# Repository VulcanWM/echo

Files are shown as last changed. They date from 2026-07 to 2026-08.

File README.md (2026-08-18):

# Echo

This is my first hardware project, in which I made a Simon Says game by designing a PCB and writing the firmware for it.

The components involved are a XIAO RP2040 as the microcontroller, 3 switches which represent the possible options the player has to press, 3 different coloured LEDs that light up when introducing the sequence, resistors to stop the LEDs from receiving too much current, and a buzzer so the game is not just vision-based but also audio-based.

There is also a CAD-designed case, consisting only of a bottom section. I felt that a top cover was unnecessary, as the buttons and LEDs need to remain clearly visible and accessible. The bottom case mainly protects the PCB while making the device easier and more comfortable to hold. There are 4 mounting holes so that the PCB can be securely attached to standoffs in the case using screws.

How the game works is:
- You press any button to start.
- It gives you a sequence of length 1 (while playing a tone and lighting up the corresponding LED).
- You then have to press the button that corresponds to the LED that just lit up.
- If you get that right, you are given a sequence of length 2, with one extra note added to the previous sequence.
- The game keeps going until you either get the sequence wrong (and hear a losing tune I created), or reach 100 rounds (and hear a victory tune I created).

I made it because I spend a lot of time on devices, so whenever I've been using one continuously for around an hour, I can take a break by playing this game. Since it's a memory game, it also helps me improve my focus.

## Images

The KiCad source files (`.kicad_pro`, `.kicad_sch`, `.kicad_pcb`) and `gerbers.zip` used to manufacture the PCB are located in the [`pcb-files`](pcb-files) folder.

This is what the schematic looks like:

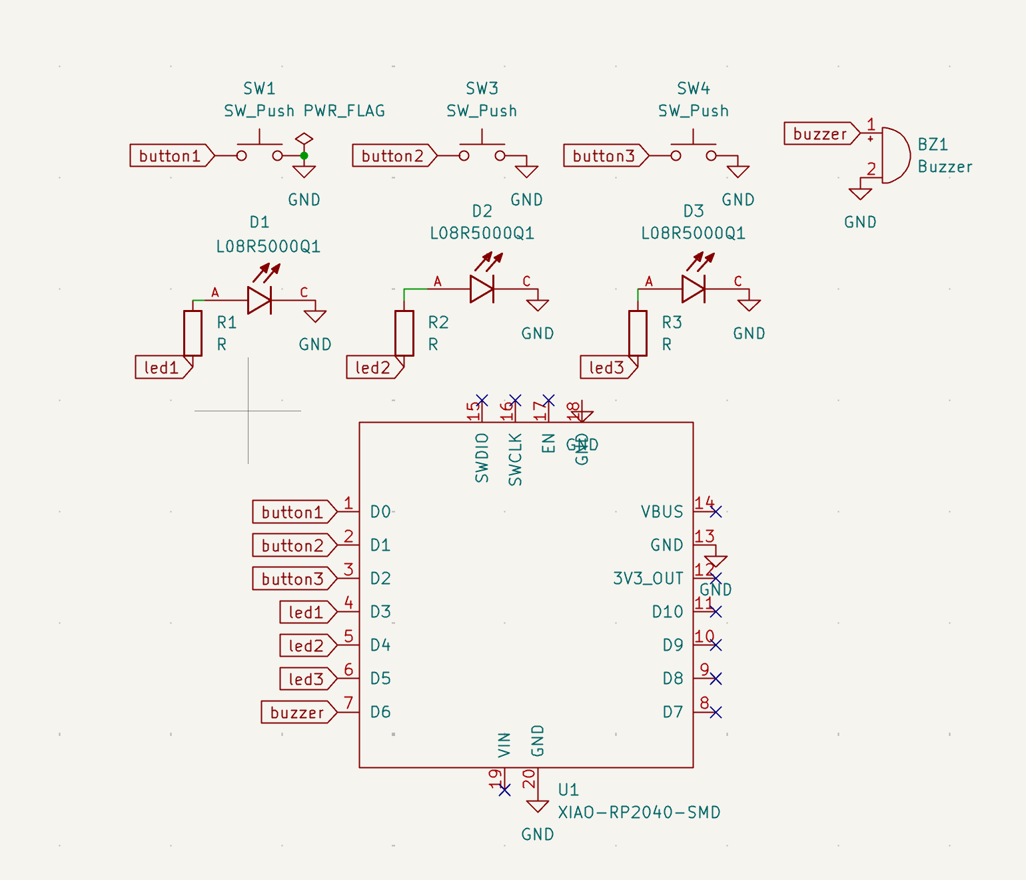
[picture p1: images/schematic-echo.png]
schematic


This is what the PCB looks like:

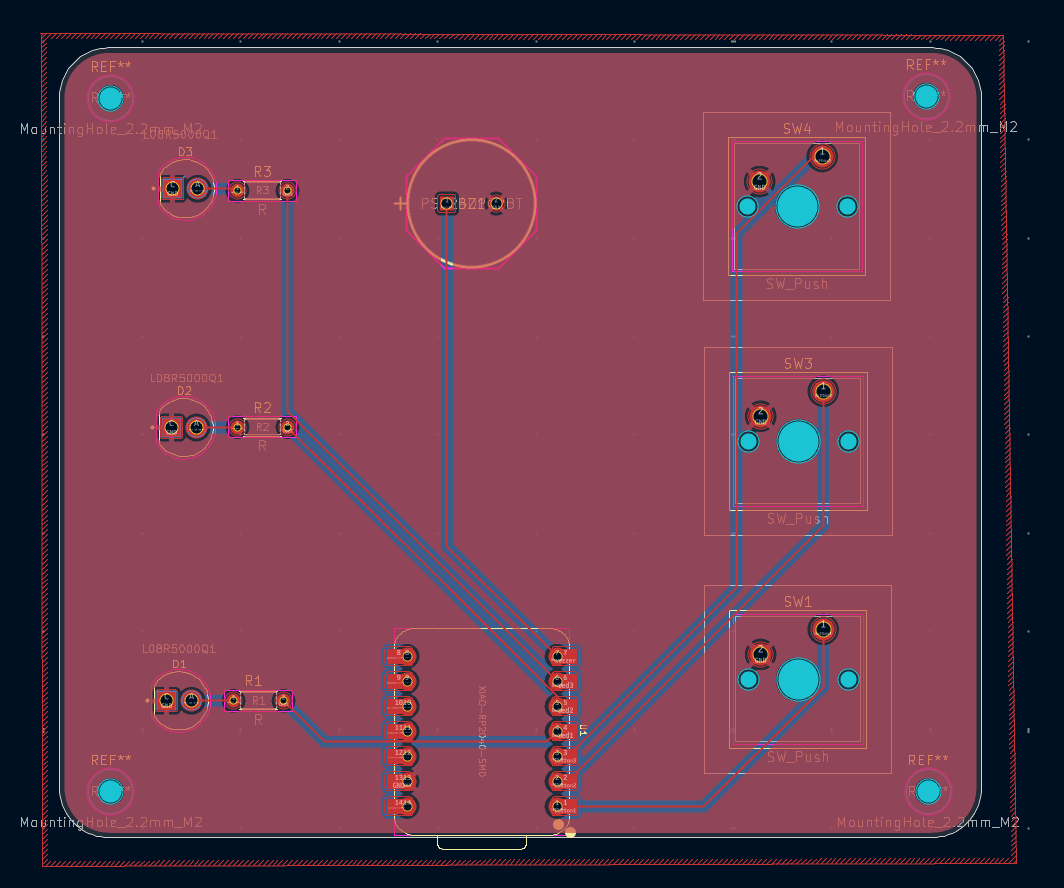
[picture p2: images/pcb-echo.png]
pcb


This is what the PCB looks like in the 3D renderer:

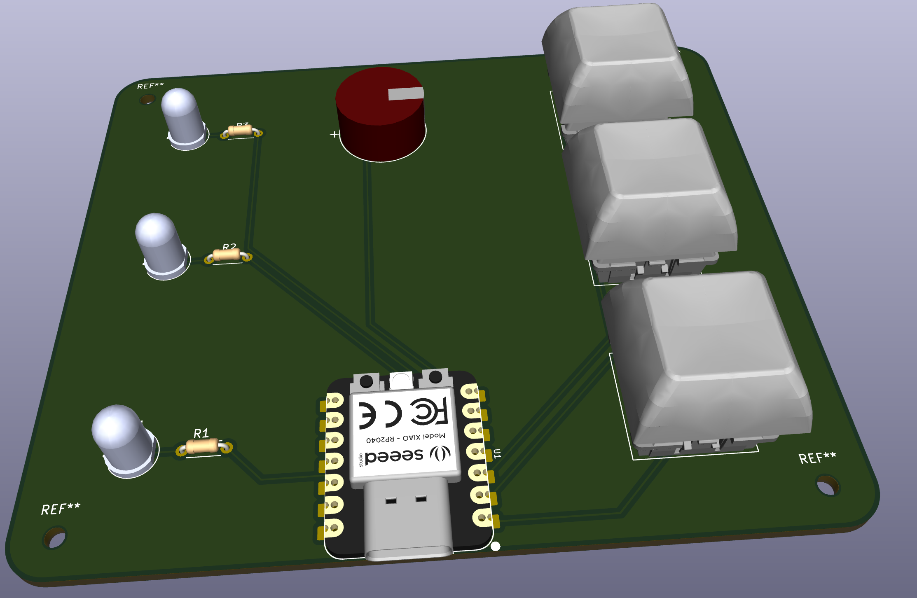
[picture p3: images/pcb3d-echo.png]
pcb 3d


The Fusion CAD source files (`.step`, `.stl`, `.f3d`) used to manufacture the case can be found in the [`case-files`](case-files) folder.

This is what the case looks like (with the PCB inside it):

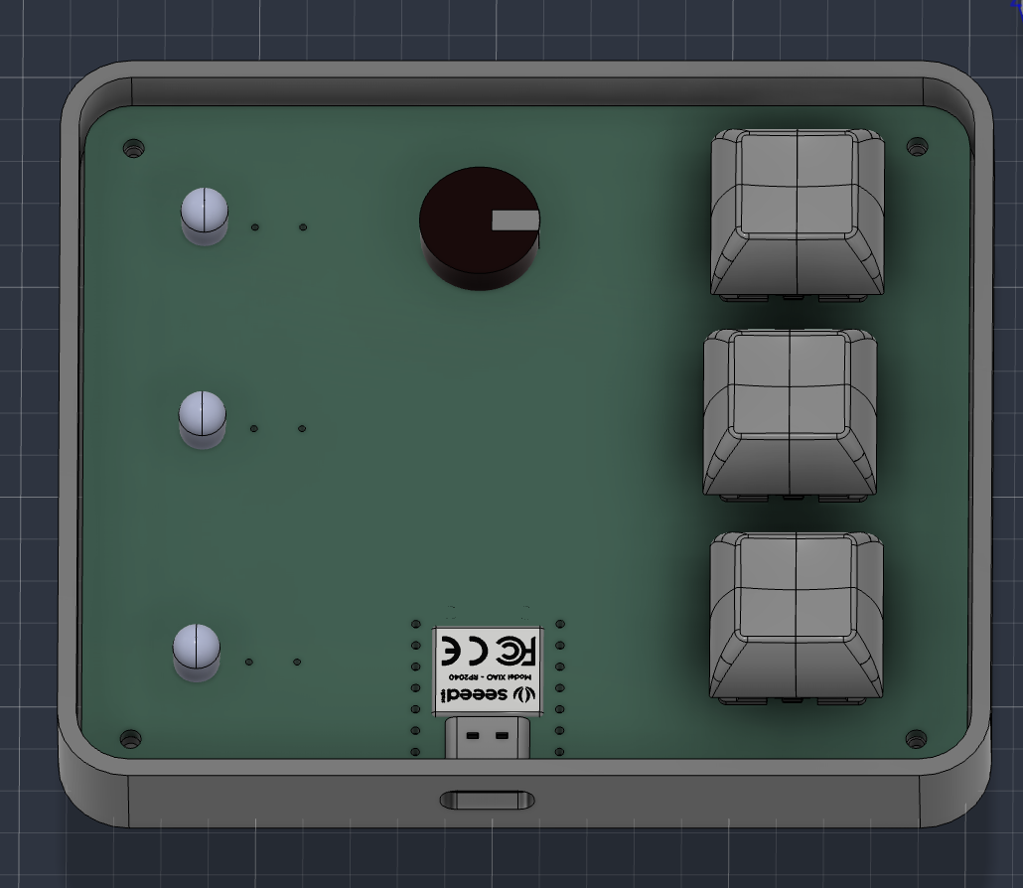
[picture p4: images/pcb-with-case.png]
pcb with case


## Firmware

The firmware contains the code for exactly what I explained in the how the game works' section and it was written in the Arduino IDE in C++. It is in the [echo.ino](https://github.com/VulcanWM/echo/blob/main/echo.ino) file.

## Assembly
1. Order the PCB using the Gerber files in the pcb-files folder and 3D print the bottom case using the files in the case-files folder. 
2. Solder the XIAO RP2040, 3 LEDs, 3 resistors, buzzer, and 3 switches onto the PCB, making sure the LEDs are inserted with the correct polarity.
3. Place the keycaps onto the three switches.
4. Position the PCB on top of the four standoffs in the case, lining up the 2.2mm PCB mounting holes with the pilot holes in the standoffs.
5. Use M2 self-tapping screws to secure the PCB to the case. The screws thread into the 1.7mm pilot holes in the standoffs.
6. Check that the XIAO RP2040 USB-C port lines up with the cutout in the side of the case and that no components or solder joints are touching the bottom of the case.
7. Connect the XIAO RP2040 over USB-C and upload the firmware from `echo.ino`.
8. Test each switch, LED, and the buzzer before playing the game.

## BOM
(Also in the [BOM.csv](https://github.com/VulcanWM/echo/blob/main/BOM.csv) file)

| Name | Qty | Link | Cost |
|---|----:|---|---:|
| Seeed Studio XIAO RP2040 | 1 | https://www.seeedstudio.com/XIAO-RP2040-v1-0-p-5026.html | $3.90 |
| Gateron Milky Pro Yellow Switches (10-pack) | 1 | https://www.aliexpress.com/item/1005004061195309.html | $4.25 |
| DSA PBT 1U Keycaps (10-pack) | 1 | https://www.aliexpress.com/item/1005012418077180.html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 | $7.21 |
| 5mm Red LED | 1 | https://www.lcsc.com/product-detail/C52034661.html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 | $0.41 |
| 5mm Blue LED | 1 | https://www.lcsc.com/product-detail/C52034724.html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 | $0.64 |
| 5mm Yellow LED | 1 | https://www.lcsc.com/product-detail/C52034720.html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 | $0.57 |
| 220Ω 1/4W Through-Hole Resistor (50-pack) | 1 | https://www.lcsc.com/product-detail/C127220.html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 | $0.57 |
| TDK PS1240P02BT Piezo Transducer | 1 | https://www.lcsc.com/product-detail/C76871.html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 | $0.22 |
| Custom PCB (5 boards) | 1 | https://jlcpcb.com | $4.00 |
| Shipping | 1 | https://jlcpcb.com | ~$3.50 |
| **Estimated Total** |  |  | **~$25.27** |

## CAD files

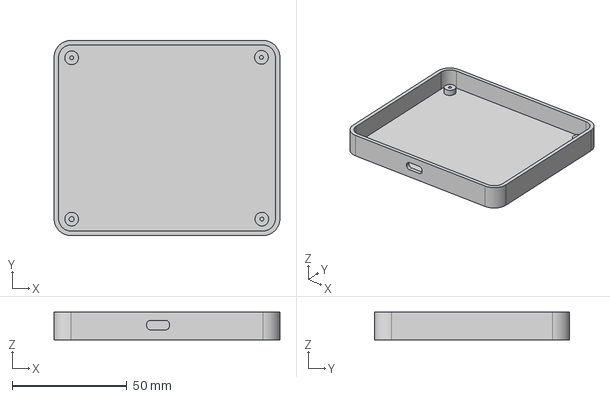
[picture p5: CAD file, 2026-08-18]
case-files/Enclosure.step
98.6 x 85.2 x 12.0 mm

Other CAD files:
case-files/Enclosure.f3d
case-files/Enclosure.stl

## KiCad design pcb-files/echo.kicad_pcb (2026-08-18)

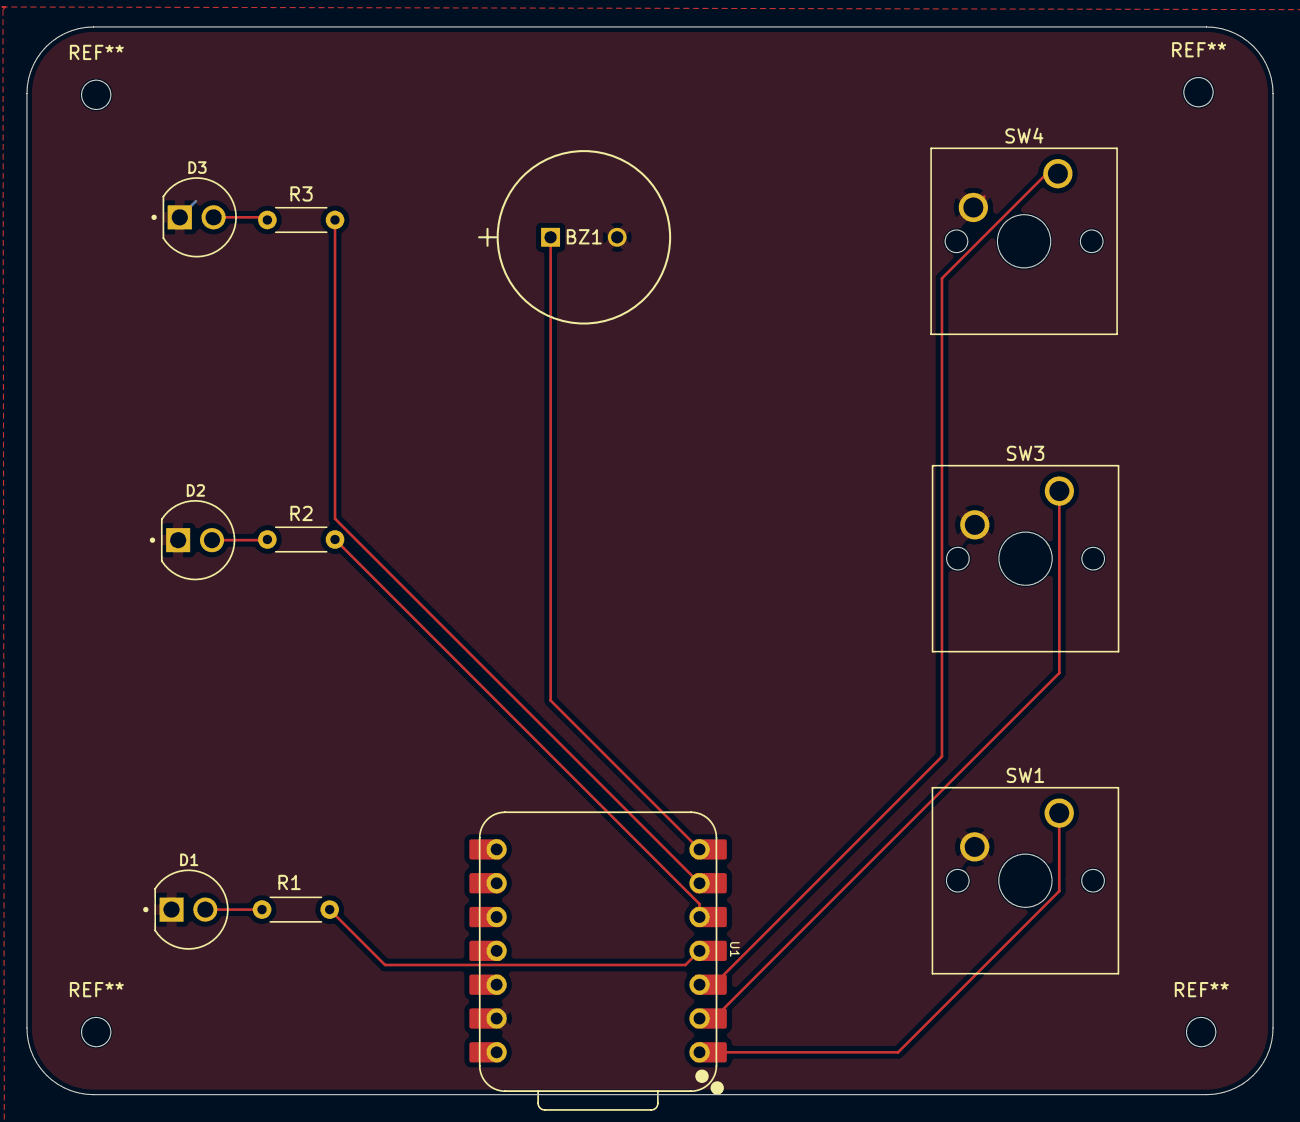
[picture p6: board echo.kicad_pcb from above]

Board: 2 copper layers, 93.6 x 80.2 mm, 11 parts (0 on the bottom side), 11 nets.

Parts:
BZ1: PS1240P02BT; XTAL_PS1240P02BT_TDK
D1, D2, D3: L08R5000Q1; LEDRD254W57D500H1070
R1, R2, R3: R; R_Axial_DIN0204_L3.6mm_D1.6mm_P5.08mm_Horizontal
SW1, SW3, SW4: SW_Push; SW_Cherry_MX_1.00u_PCB
U1: XIAO-RP2040-SMD; XIAO-RP2040-DIP

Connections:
GND: BZ1.2, D1.C, D2.C, D3.C, SW1.2, SW3.2, SW4.2, U1.13 (GND)
unnamed: D1.A, R1.1
unnamed: D2.A, R2.1
unnamed: D3.A, R3.1
button1: SW1.1, U1.1 (D0)
button2: SW3.1, U1.2 (D1)
button3: SW4.1, U1.3 (D2)
buzzer: BZ1.1, U1.7 (D6)
led1: R1.2, U1.4 (D3)
led2: R2.2, U1.5 (D4)
led3: R3.2, U1.6 (D5)

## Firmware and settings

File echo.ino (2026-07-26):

int button1 = D0;
int button2 = D1;
int button3 = D2;

int led1 = D3;
int led2 = D4;
int led3 = D5;
int leds[] = {led1, led2, led3};

int buzzer1 = D6;

bool gameStarted = false;
int round = 0;

int sequence[100]; // win at 100
int inputIndex = 0;

void newRound(){
  delay(500);
  
  int newColour = random(3);
  sequence[round-1] = newColour;
  for (int i = 0; i < round; i++){
    int currentColour = sequence[i];
    int frequency = (currentColour+1) * 300;
    tone(buzzer1, frequency, 1000);
    digitalWrite(leds[currentColour], HIGH);
    delay(1000);
    digitalWrite(leds[currentColour], LOW);
    if (i != (round-1)){
      delay(500);
    }
  }
}

void loseTune(){
  tone(buzzer1, 900, 500);
  delay(500);
  tone(buzzer1, 800, 500);
  delay(500);
  tone(buzzer1, 700, 500);
  delay(500);
  tone(buzzer1, 600, 500);
  delay(500);
  tone(buzzer1, 500, 1000);
  delay(1000);
}

void victoryTune(){
  tone(buzzer1, 500, 500);
  delay(500);
  tone(buzzer1, 600, 500);
  delay(500);
  tone(buzzer1, 700, 500);
  delay(500);
  tone(buzzer1, 800, 500);
  delay(500);
  tone(buzzer1, 900, 500);
  delay(500);
  tone(buzzer1, 900, 500);
  delay(500);
  tone(buzzer1, 900, 500);
  delay(500);
}

void waitForRelease() {
  while (
    digitalRead(button1) == LOW ||
    digitalRead(button2) == LOW ||
    digitalRead(button3) == LOW
  ) {
    delay(5);
  }

  delay(20);
}

void setup() {
  pinMode(button1, INPUT_PULLUP);
  pinMode(button2, INPUT_PULLUP);
  pinMode(button3, INPUT_PULLUP);

  pinMode(led1, OUTPUT);
  pinMode(led2, OUTPUT);
  pinMode(led3, OUTPUT);

  pinMode(buzzer1, OUTPUT);

  Serial.begin(9600);

  randomSeed(analogRead(0));
}

void loop() {
  if (gameStarted == false) {
    if (digitalRead(button1) == LOW || digitalRead(button2) == LOW || digitalRead(button3) == LOW){
      round = 1;
      gameStarted = true;
      newRound();
      inputIndex = 0;
      waitForRelease();
    }
  } else {
    bool buttonPressed = false;
    int pressedButton = 0;
    if (digitalRead(button1) == LOW){
      buttonPressed = true;
      pressedButton = 0;
    } else if (digitalRead(button2) == LOW){
      buttonPressed = true;
      pressedButton = 1;
    } else if (digitalRead(button3) == LOW){
      buttonPressed = true;
      pressedButton = 2;
    }

    if (buttonPressed == true){
      int frequency = (pressedButton+1)*300;
      if (sequence[inputIndex] == pressedButton){
        inputIndex += 1;
        tone(buzzer1, frequency, 500);
        digitalWrite(leds[pressedButton], HIGH);
        delay(500);
        digitalWrite(leds[pressedButton], LOW);
        waitForRelease();
        if (inputIndex == round){
          if (round == 100){
            victoryTune();
            gameStarted = false;
            return;
          }
          round += 1;
          inputIndex = 0;
          newRound();
        }
      } else {
        for (int i = 0; i < round; i++){
          int currentColour = sequence[i];
          int frequency = (currentColour+1) * 300;
          tone(buzzer1, frequency, 500);
          digitalWrite(leds[currentColour], HIGH);
          delay(500);
          digitalWrite(leds[currentColour], LOW);
          if (i != (round-1)){
            delay(250);
          }
        }
        loseTune();
        gameStarted = false;
      }
    }

    waitForRelease();
  }
}

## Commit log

2026-07-25 Started working on the code
    - Configured the input and output pins in the setup subroutine
    - Created a subroutine which will add a new colour to the current sequence and play it to the player
    - Registered the game being started by the press of any button
    - Once the game has started, registered the button being pressed and checked whether it is the correct button or not
    - Moving onto the next round if the button pressed was correct
    [echo.ino]
2026-07-25 feat: switched highs to lows as input_pullup is inverted
    [echo.ino]
2026-07-30 Create BOM.csv with component details
    Added a Bill of Materials (BOM) with components, quantities, links, and costs.
    [BOM.csv]
2026-07-30 Create README.md for Echo hardware project
    Added project description and BOM for Echo game.
2026-07-30 Create pcb folder
2026-07-30 Update README with KiCad files and PCB images
    Added information about KiCad source files and PCB images.
2026-08-03 Fix link to PCB files folder in README
2026-08-13 updated README with case design information
2026-08-18 added 10 pack switches to bom instead of 30 pack
    [BOM.csv]
2026-08-18 added kicad files + gerbers
    [echo.kicad_pcb]
2026-08-18 added cad files
    [Enclosure.f3d, Enclosure.step, Enclosure.stl]
